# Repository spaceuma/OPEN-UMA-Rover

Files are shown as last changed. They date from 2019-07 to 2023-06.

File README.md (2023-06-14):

# UMA Open Source Rover ROS2
Open hardware and software rover developed by Malaga University

*Authors:* C.J. Pérez del Pulgar, Ricardo Sánchez Ibáñez, Patricio López Lupiañez, Francisco de Asís Delgado Rivero, Laura Marta Mantoani and Danil Rivero Pavlenko

*Contact info:* carlosperez@uma.es

*Affiliation:* University of Malaga, [Space Robotics Lab](https://www.uma.es/robotics-and-mechatronics/info/107542/robotica-espacial/)

## Overview
The OpenUmaRov is an open source mobile robotic platform that allows anyone to build it with a maximum cost of 700€, taking into account that the Reach M+ GPS can be replaced with whatever GPS that works with NMEA sentences: just connecting it to the Raspberry Pi through USB port, thanks to the ROS node the GPS can publish NMEA sentences in different topics. This means that, replacing the Reach M+ with a cheaper one, the rover can be built with a maximum cost of 500 €. 

The platform is based on commercial components that can be acquired by Internet. This project involves students and researchers to improve the development of the platform. Moreover, it can be used for teaching and research activities that involves mechanical, engineering, software, electronics and robotics.

## ROS2 

An adaptation of the original code to ROS2 Humble has been developed. This enables the use of the Rover with the Middleware ROS2. 

rover_ros2

### Guide

First you need to setup your package and your workspace. Use the package in this repository inside the workspace.

Then make sure to source the package and build the workspace.
```
 source install/setup.bash
 colcon build
```

### Troubleshooting

Issues might appear while setting up your workspace.

- setuptools 58.2 for colcon build sterr output error due to deprecated version.

https://answers.ros.org/question/396439/setuptoolsdeprecationwarning-setuppy-install-is-deprecated-use-build-and-pip-and-other-standards-based-tools/

```
pip install setuptools==58.2.0
```

Install serial
Guide: https://create.arduino.cc/projecthub/ansh2919/serial-communication-between-python-and-arduino-e7cce0

```
pip install pyserial
```

Info. about the Twist format for the msg variable which holds the data received from the topic.

http://docs.ros.org/en/noetic/api/geometry_msgs/html/msg/Twist.html

### Running the node

To run the node once sourced and built.

```
ros2 run rov_node_pkg ROS2UMARov
```

## Rover URDF

In order to test the Rover in a simulated environment, a URDF file of the OpenUMARov has been developed.

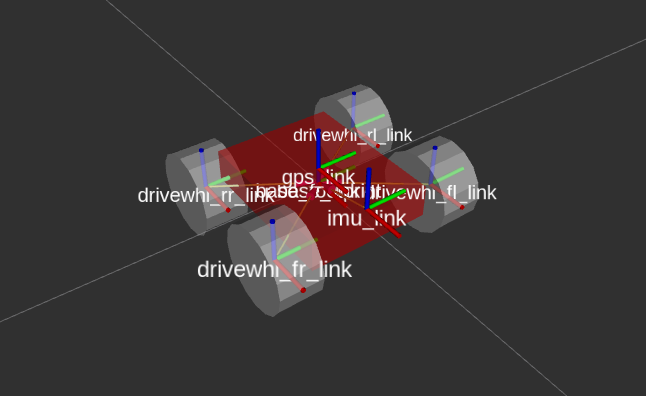
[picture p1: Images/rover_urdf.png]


## Rover SDF

To implement Rover simulations on Gazebo, it is necessary to develop the SDF Model of it. 

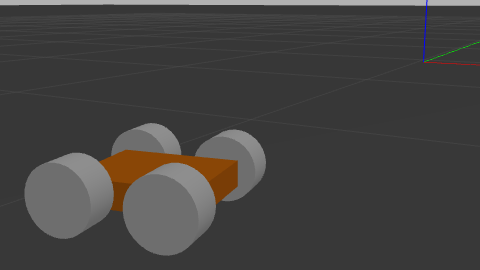
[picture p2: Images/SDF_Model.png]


This model uses the following plugins.

- GPS Plugin to simulate such in the simulation environment.
- IMU to simulate the orientation of the Rover.
- Differential drive Model to implement the movement of the Rover 
- Joint State Publisher to know wheels state.

An alternative for NAV2 has been implemented as en extended model.

## Joystick Control

A good way to easily control the Rover is by using the Teleoperation Joystick Control.

By default, it uses the ```ps3_config.yaml``` file.

To test this package a F-710 Game Pad with a USB with Bluetooth connection was used, even though the ```.config``` file is for the PS3 Joystick. If you wish to use a Bluetooh joystick control, you have to edit the directory of the connection to rather the Bluetooth direction, using a USB connection is recommended nonetheless.

To use it with the PC the following changes should be done:

- Add permissions to read/write Serial: 

```
sudo adduser $USER $(stat --format="%G" /dev/ttyACM0)
```

- Build the package with the following command:

```
colcon build --allow-overriding teleop_twist_joy
```

PS3 is default, to run for another config (e.g. xbox) use this:

```
ros2 launch teleop_twist_joy teleop-launch.py
```

Note: this launch file also launches the joy node so do not run it separately.

Only if required:

- Uninstall the default joystick teleop. from ROS2 Lib. Head to opt/ros/lib and remove the file teleop_twist_joy. 
- The last step is due to ROS2 using the config. of the default driver and its parameters instead of your package.
- Launch the driver as normally.

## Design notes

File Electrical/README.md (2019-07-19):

# OPEN-UMA-Rover/Electrical
In this folder there are the files for the PCB board in Eagle, version 7.6.0.

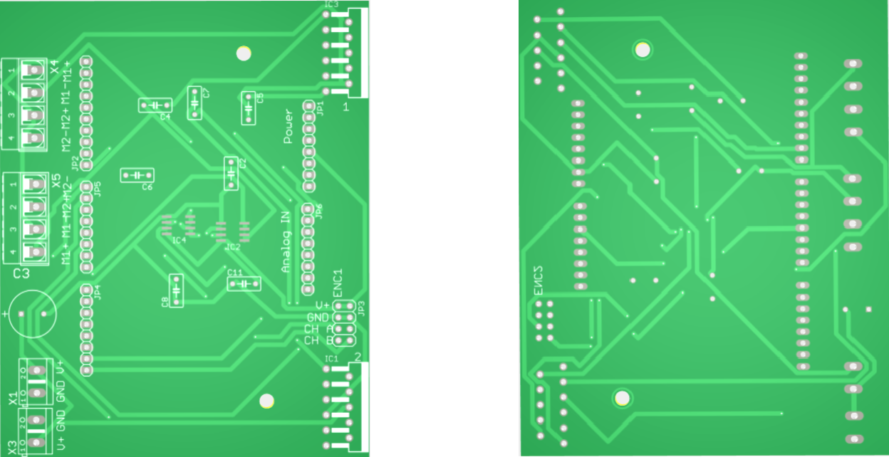
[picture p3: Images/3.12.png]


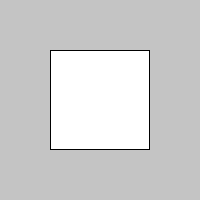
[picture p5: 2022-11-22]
Software/SDF_URDF/OpenUMA_NAV2/maps/empty_room.png

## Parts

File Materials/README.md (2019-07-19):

# OPEN-UMA-Rover
In this folder there is an Excel file which includes all the componentes needed to build the platform. Also, it is included the price, the link to buy each component and the Farnell code in case it exists.

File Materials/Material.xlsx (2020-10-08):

Component | Quantity | Farnell | Link to buy | PRICE (€)
Chasis + 4 wheels + 4 engines | 1 |  |  | 247.64
Encoder Lynxmotion | 2 |  | https://www.robotshop.com/es/es/codificador-motor-cuadratura-v2-lynxmotion-con-cable.html | 69.44
Arduino Mega 2560 | 1 |  |  | 16.95
Fuse holder | 1 |  |  | 0.5
Fuse 4A | 1 |  |  | 0.1
Connector 2.5mm | 1 |  |  | 1.06
Rechargeable battery NiMH 12 Vdc 2800 mAh | 1 |  |  | 48.99
Capacitor 1uF | 1 | 2112910 |  | 0.28
Capacitor 220uF | 1 | 1219481 |  | 0.75
Capacitor 10nF | 4 | 1141772 |  | 0.76
Capacitor 1nF | 2 | 1902259 |  | 0.78
LM18200T | 2 | 1468979 |  | 31.16
ACS712-LC | 2 | 1329623 |  | 8.18
Pin header 2X04 | 1 | 1593441 |  | 0.04
Connector AK500/2 | 2 | 2493622 |  | 0.6
Connector AK500/4-H | 2 | 2490940 |  | 3.8
Pin header 1X08 | 4 | 1593416 |  | 1.32
Pin header 1X10 | 1 | 1593417 |  | 0.4
GPS Reach M+ | 1 |  | https://emlid.com/reach/ | 227.78
Raspberry PI 3 B+ | 1 | 2842228 | https://es.farnell.com/raspberry-pi/rpi3-modbp/ordenador-monoplaca-raspberry/dp/2842228 | 32.46
Regulador Step-Down 5V/3.2A (D36V28F5) | 1 |  | https://tienda.bricogeek.com/convertidores-de-voltaje/1335-regulador-step-down-5v32a-d36v28f5.html | 10.95
 |  |  | TOTAL | 703.94
 |  |  |  |  | TOTAL

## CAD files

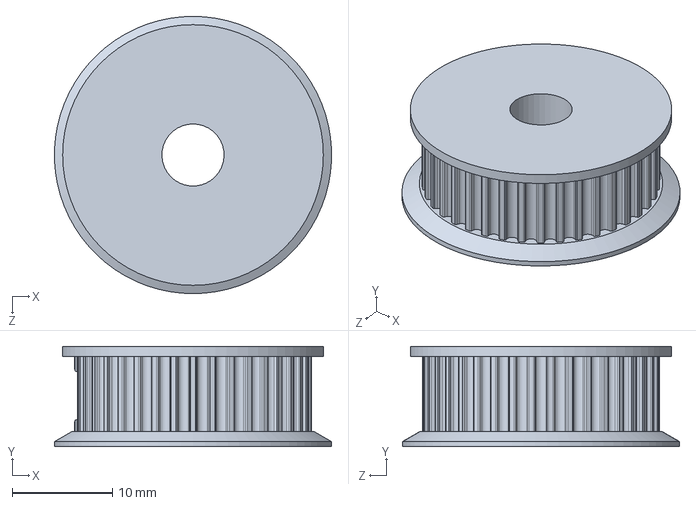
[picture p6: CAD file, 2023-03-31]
Materials/Impresiones/Engranajes Correa/Engranaje.SLDPRT
27.6 x 10.0 x 27.7 mm

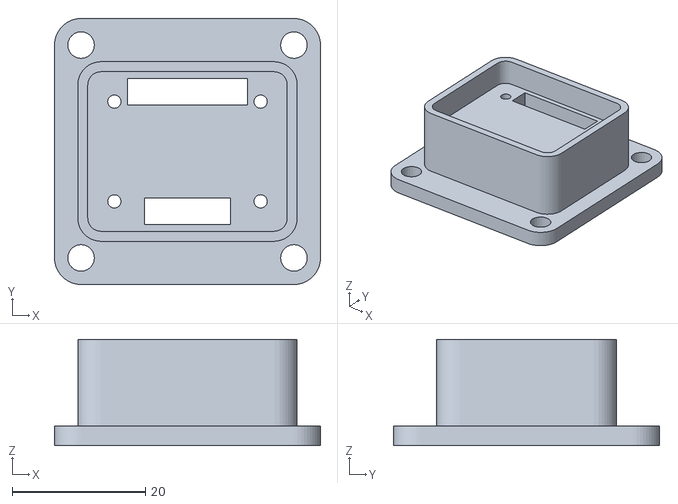
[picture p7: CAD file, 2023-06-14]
Materials/Impresiones/imu_holder.stl
40.0 x 40.0 x 16.0

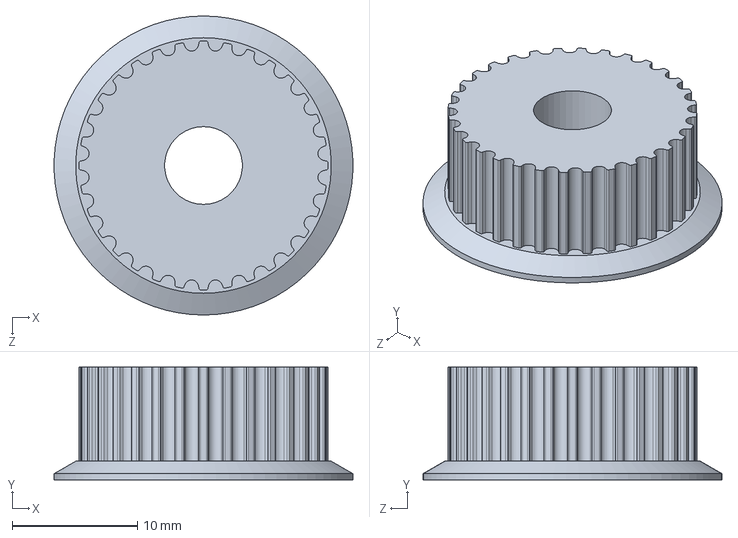
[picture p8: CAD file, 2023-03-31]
Materials/Impresiones/Engranajes Correa/gt2-parametric-pulley.SLDPRT
23.8 x 9.00 x 23.8 mm

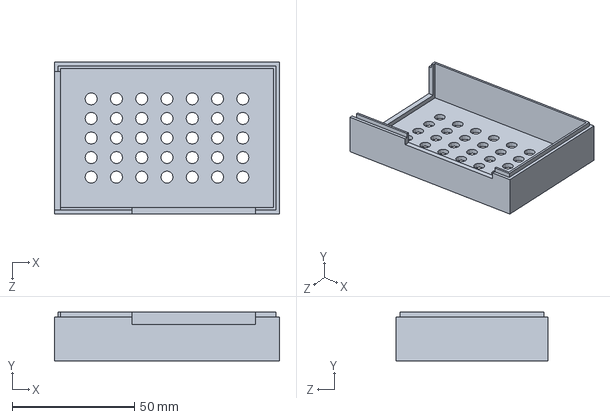
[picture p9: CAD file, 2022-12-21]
Materials/Impresiones/SoporteRasp3.SLDPRT
92.0 x 20.0 x 62.0 mm

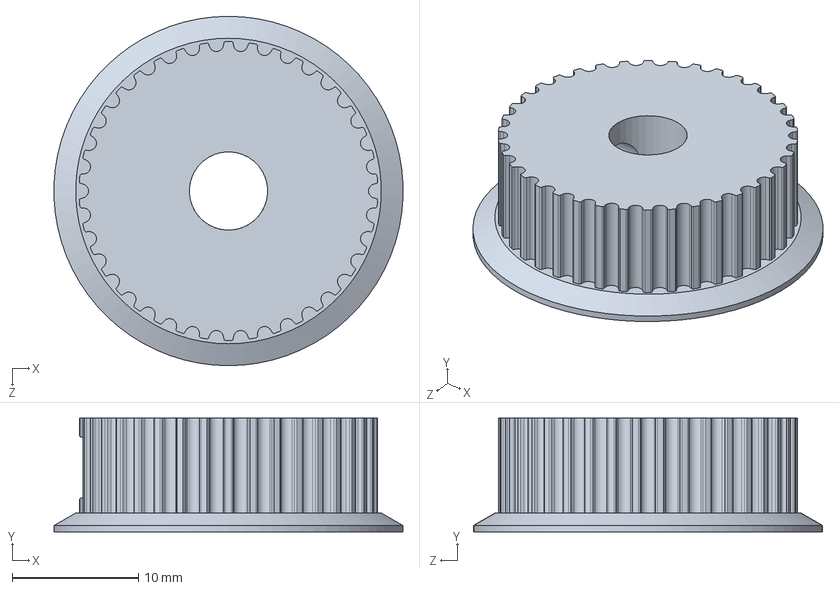
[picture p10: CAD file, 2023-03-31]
Materials/Impresiones/Engranajes Correa/Engranaje_Sin_Borde.SLDPRT
27.6 x 9.00 x 27.7 mm

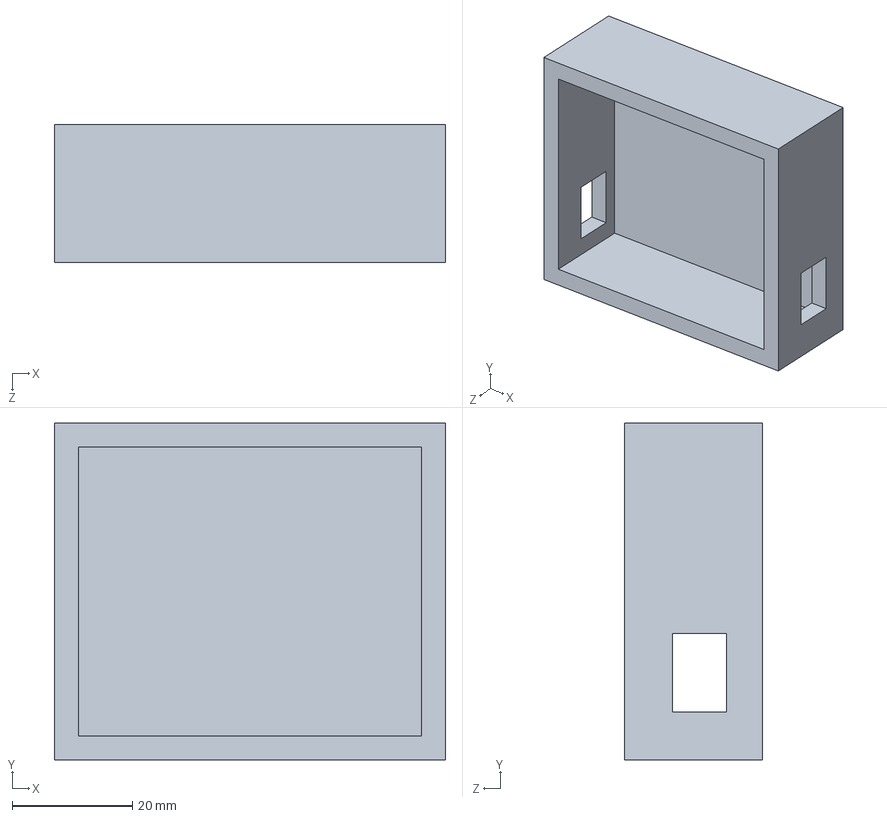
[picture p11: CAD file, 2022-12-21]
Materials/Impresiones/gps_corregido.SLDPRT
65.0 x 56.0 x 23.0 mm

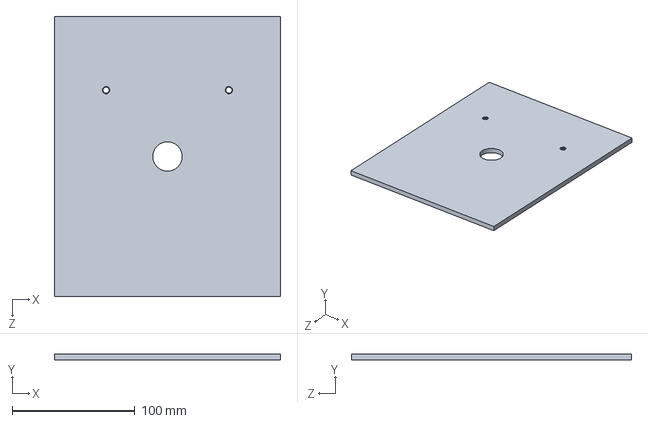
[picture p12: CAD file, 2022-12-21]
Materials/Impresiones/tapa_principal.SLDPRT
184.0 x 5.00 x 228.0 mm

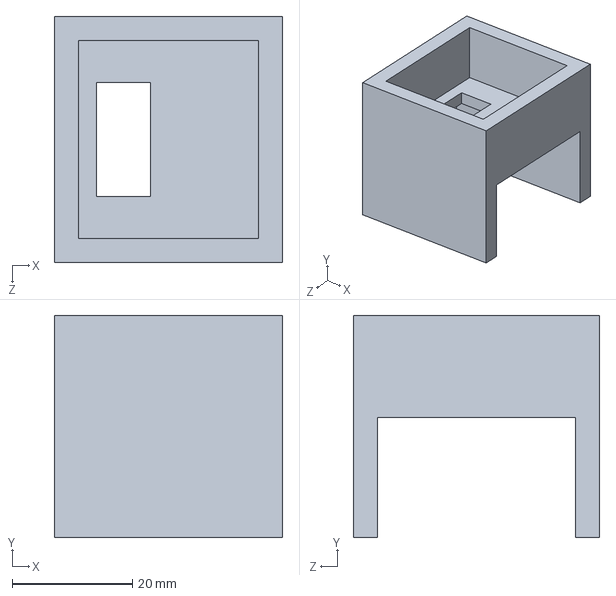
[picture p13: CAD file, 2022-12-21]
Materials/Impresiones/imu_corregido.SLDPRT
38.0 x 37.0 x 41.0 mm

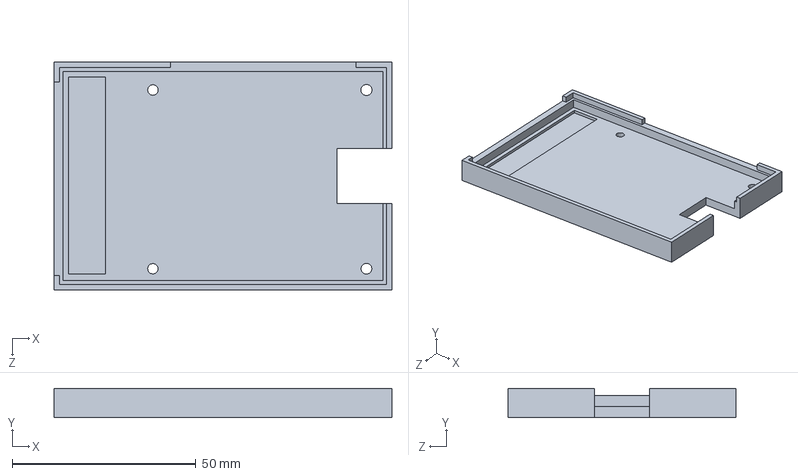
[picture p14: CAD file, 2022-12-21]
Materials/Impresiones/SoporteRasp3.1.SLDPRT
92.0 x 8.00 x 62.0 mm

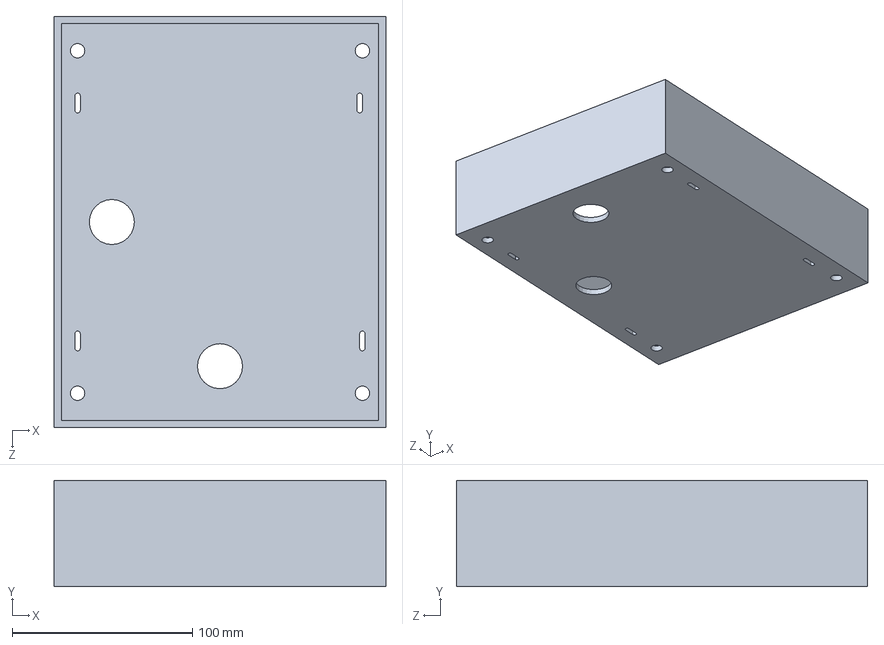
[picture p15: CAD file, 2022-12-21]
Materials/Impresiones/caja_principal.SLDPRT
184.0 x 59.0 x 228.0 mm

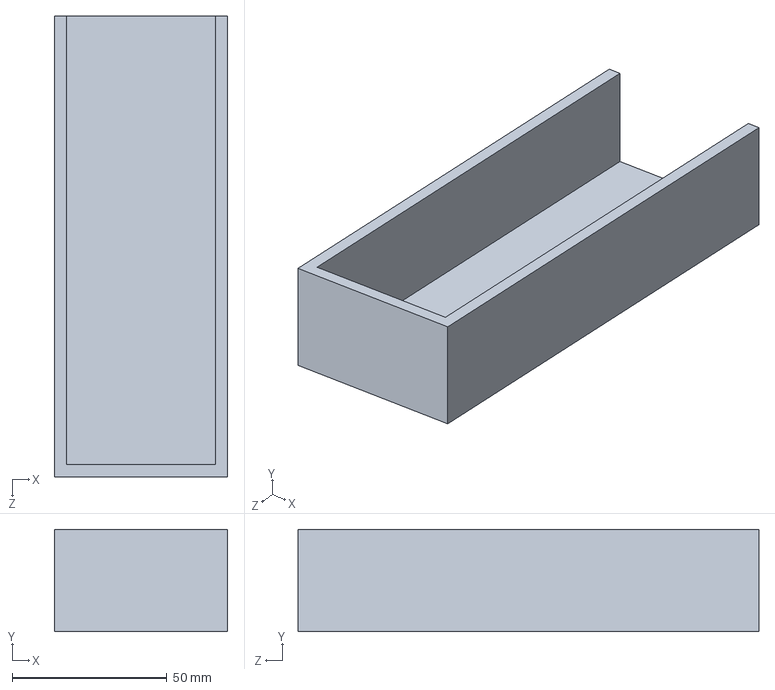
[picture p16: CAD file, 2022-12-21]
Materials/Impresiones/bateria.SLDPRT
56.0 x 33.0 x 149.0 mm

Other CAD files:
Materials/Impresiones/SoporteRasp3.1.STL
Materials/Impresiones/SoporteRasp3.STL

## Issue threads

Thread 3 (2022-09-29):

Implementar en ROS2 el control del vehículo

carlibiri, 2022-09-29:
Adaptar el código Python del nodo ROS para que se pueda conectar con Nav2.
Lo que no se pueda conectar con Nav2 se deja en un topic por si nos sirviera más adelante.

carlibiri, 2022-10-06:
Pendiente probarlo con el vehículo real.

Danilrivero, 2022-10-10:
Se ha probado el funcionamiento del nodo cargando a su vez el archivo .ino en la Mega 2560 **y funciona**.

Debido a los continuos cambios de HW que ha sufrido el Rover por los proyectos que ha tenido, indicar que el cambio más importante es que el orden de los encoders conectados a la Arduino es inverso, donde la posición del encoder 1 va la del 2 y viceversa.

carlibiri, 2022-10-13:
Las ruedas se mueven.

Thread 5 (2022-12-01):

Diseñar y fabricar caja que contenga los sensores

carlibiri, 2022-12-01:
Diseñar y fabricar caja que contenga los sensores fuera del chasis del rover.

Danilrivero, 2022-12-07:
Para realizar la caja se ha decidido dieñar de forma modular para que la impresión de todas las piezas sea más cómoda. Luego colocaré todo en su posición concreta y lo pondré a prueba.

Se tienen las siguientes piezas:

- [x] Caja de Raspberry Pi 4
- [x] Caja de batería
- [x] Caja y soporte de IMU
- [ ] Caja de GPS
- [ ] Caja principal
- [ ] Tapa de Caja

La idea es tener compartimentos modulares para cada cosa. Se tendría una caja que taparía el compartimento inferior de Arduino y PCB. Habrían unos orificios por donde entrarían 4 cables:

1. Cable de Arduino
2. Alimentación USB-C
3. Alimentación principal
4. Alimentación del HUB

Esta caja debe de ser robusta y encima habría una tapa con los soportes de GPS e IMU para que a través de un orificio se comuniquen con la RP también. Actualmente ya hay piezas hechas y estoy en proceso de realizar el resto.

Danilrivero, 2022-12-15:
Todas las piezas están hechas e impresas salvo la caja principal que es la siguiente:

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

Tarda un total de 34h en imprimirse y la impresora sigue dando problemas. Voy a desmontar el calentador del extrusor aunque no se si es la solución intentar montarlo de nuevo todo. Voy a hablar con la gente en la nave para ver si puedo poner la pieza ahí a imprimir.

Danilrivero, 2022-12-21:
Todas las piezas diseñadas e impresas.

Danilrivero, 2022-12-21:
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

Closed 2023-01-26.

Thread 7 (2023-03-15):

Gomas de agarre para OPENUMA

Danilrivero, 2023-03-15:

Danilrivero, 2023-03-15:
Estabamos analizando como hacer que las ruedas se conecten para que tengan tracción. Entre los ejes de las ruedas apenas hay sitio y no es viable añadir nada. Hemos pensado en las siguiente gomas que irían entre las ruedas a forma de oruga de tanque:

https://www.amazon.es/Elasticas-Resistencia-Ejercicios-entrenamiento-fisioterapia/dp/B016A9IUWY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

La circunferencia en el OPENUMA es de 69 cm entre las ruedas (distancia entre centro de circunferencias * 2 + 2*pi*R) y estas gomas son de 60 cm, así que vienen genial para que queden estiradas y agarradas, y tienen relieve suficiente además del que nosotros le añadamos para poder generar una buena tracción.

He analizado opciones de orugas de tanque directamente pero son o caras o no existe alguna sin sujeciones internas pensadas para tanques unicamente. Creo que ese tipo de gomas son la opción más factible, luego sobre ella podemos añadir algún tipo de relieve.

SSUrdiales, 2023-03-16:
He estado mirando diferentes alternativas para la cadena. Creo que hay que buscar que tenga rugosidad para que agarre bien al terreno:

https://www.amazon.es/Harilla-Montaje-Pl%C3%A1stico-Extra%C3%ADble-Bricolaje/dp/B07QQNC9WW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

https://www.amazon.es/PRDECE-neum%C3%A1tico-Accesorios-neum%C3%A1ticos-veh%C3%ADculos/dp/B0BCDZ3F9T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

https://www.amazon.es/DNKKQ-Accesorios-Calidad-Cadena-orugas/dp/B09J2HLFFX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

carlibiri, 2023-03-16:
Intentamos ver si podemos encajar algo entre los ejes.

Danilrivero, 2023-03-21:
Considerando la distancia entre ejes, se tiene una distancia de 162 mm, por tanto la goma debe tener las siguientes características:

- 324 mm de longitud

- 6-8 mm de ancho

He intentado plantear la posibilidad de desarrollarlo usando la goma de la impresora que es resistente y puedo crear la dentadura a forma de engranaje en los dos ejes para una mayor sujeción.

Voy a buscar en Internet modelos de gomas con esas características.

Danilrivero, 2023-03-22:
Por un lado se ha probado a pegar la goma y estamos a la espera de que seque para echarlo a rodar.

Por otro he analizado las correas cerradas:

1. El tamaño de la correa debe ser de como mínimo 324 mm, por lo tanto el siguiente valor **estándar** de correas es el de 400 mm.

2. La longitud entre ejes es de 162 mm, por lo tanto la distancia total es de 324 mm. los otros 76 mm se tratan de los dos medio arcos de los engranajes, por lo que la mitad del perimetro de cada engranaje debe ser de 38 mm.

3. 76 mm = 2*pi*r -> r = 12.09 mm, por tanto el diametro del engranaje debe ser de 24 mm. Lo cual es un tamaño muy factible y que voy a rediseñar.

He encontrado varias opciones en Amazon que llegan rápido:

- La más barata y con mas unidades de correas de 400 mm:

https://www.amazon.es/distribuci%C3%B3n-accesorios-impresora-GT2-6-400MM-transmisi%C3%B3n/dp/B085QH1C4Y

- El resto de opciones son más caras:

https://www.amazon.es/correa-dentada-cerrada-sincronizada-longitud/dp/B07RWM2SPN?th=1

- En otras páginas Web se pueden comprar por unidad más baratas:

https://createc3d.com/es/correas-y-poleas/649-correa-cerrada-gt2-200-dientes-400-mm-longitud.html

En AliExpress las que más pronto llegan son en Abril-Mayo y valen casi que lo mismo.

carlibiri, 2023-03-22:
Acabo de pedir el primero de amazon, llegarán el lunes...

El mié, 22 mar 2023 a las 11:22, Danil Pavlenko ***@***.***>)
escribió:

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

--
____________________________________________________________________________

Carlos J. Pérez del Pulgar Mancebo
Space Robotics Lab
Department of Systems Engineering and Automation
UNIVERSIDAD DE MALAGA
www.isa.uma.es/cperez
____________________________________________________________________________

Danilrivero, 2023-03-22:
Los engranajes a utilizar que he descrito son los siguientes:

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

Se trata de un GT2 de 42 dientes, que es lo ideal para la correa de 400 mm.

Los tornillos prisioneros son los siguientes que debo buscar alguna opción más barata:

- Una caja con todo tipo de 20 piezas incluyendo el nuestro:

https://www.amazon.es/Bigxin-Tornillos-Prisioneros-Hexagonal-Prisionero/dp/B092ZG9QZR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

- 10 piezas de las que necesitamos pero caro:

https://www.amazon.es/sourcing-map-Tornillos-prisioneros-hexagonales/dp/B07GZD36YP

Voy a buscar opciones más baratas para mañana en Farnell o Mouser

carlibiri, 2023-03-22:
Pedida la caja....

El mié, 22 mar 2023 a las 14:54, Danil Pavlenko ***@***.***>)
escribió:

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

--
____________________________________________________________________________

Carlos J. Pérez del Pulgar Mancebo
Space Robotics Lab
Department of Systems Engineering and Automation
UNIVERSIDAD DE MALAGA
www.isa.uma.es/cperez
____________________________________________________________________________

Danilrivero, 2023-03-23:
He conseguido una correa de las que se han pedido para probarla y en efecto he verificado que los engranajes usados son correctos, he corregido los tamaños y los dientes para que ahora si funcione.

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

La correa queda bastante tensa y el eje de la rueda entra bien, así que solo queda esperar a que lleguen más correas y verificar su montaje completo para salir.

carlibiri, 2023-03-30:
@Danilrivero sube el diseño de la pieza al repositorio de openUMA.

Closed 2023-04-11.

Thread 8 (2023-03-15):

IMU BNO055 para OPENUMAROV

Danilrivero, 2023-03-15:

Danilrivero, 2023-03-15:
Tal y como hemos comentado con Laura, hace falta una nueva IMU con la idea de que tenga Driver de ROS2 ya hecho para su uso directo y más cómodo. La chica del TFG propusó la BNO055 que en efecto tiene Driver de ROS2.

https://tienda.bricogeek.com/medicion-inercial-imu/802-sensor-inercial-absoluto-9-dof-bno055.html

He probado el paquete y parece que está todo en orden y funcionaría con adaptador UART to USB:

https://github.com/flynneva/bno055

Siendo el adaptador el siguiente:

https://www.amazon.es/TECNOIOT-CP2104-Connector-Module-Converter/dp/B07N978W56

Con el siguiente conexionado con el adaptador:

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

En caso de que necesite Drivers para detectar el USB son los siguientes:

https://www.silabs.com/developers/usb-to-uart-bridge-vcp-drivers

Laura ha comunicado ya todo esto para su compra pero lo dejo aquí para que se quede guardado.

Danilrivero, 2023-03-15:
Sería conveniente desarrollar un modelo 3D a imprimir a forma de Wrapper para dejar la IMU fijada en una posición dentro del tanque o el OPENUMA, siendo el CAD de la IMU para tener un modelo en el que basarse el siguiente:

https://grabcad.com/library/adafruit-bno055-1

carlibiri, 2023-03-30:
Llega el Viernes...

carlibiri, 2023-04-20:
Pendiente probarla para comprar otra...

Danilrivero, 2023-04-21:
He verificado que la IMU funciona correctamente mediante un pequeño código de prueba en Arduino:

[imu_bno.zip](https://github.com/spaceuma/OPEN-UMA-Rover/files/11294345/imu_bno.zip)

Echando a correr el driver a una velocidad de 9600 baudios me surge el siguiente problema.

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

He dado todos los permisos debidamente para que el adaptador no tenga problemas para conectarse, aunque sigue ocurriendo. He escrito un issue en el repositorio oficial para recibir alguna ayuda ya que parece que la comunicación no sucede de forma bidireccional.

Danilrivero, 2023-04-24:
He conseguido solucionar el problema.

El problema siguiendo mi issue en https://github.com/flynneva/bno055 es que parece que en la comunicación UART la recepción de datos no era del tamaño de bytes que debía ser. He corregido dicho error y crearé un repositorio con esta información para que quede almacenado.

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

A la espera de verificar todo aunque este issue quedaría resuelto.

Danilrivero, 2023-04-25:
He creado un repositorio para toda la información, cambios y drivers aunque no creo que fueran los drivers el problema sino la recepción de bytes.

Danilrivero, 2023-04-27:
Resultado final:

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

Soporte con tornillos para fijar la IMU.

Closed 2023-04-27.

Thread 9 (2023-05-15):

Mejoras generales para ultimar OPENUMA Rover

Danilrivero, 2023-05-15:

Danilrivero, 2023-05-15:
[Teleoperation_Platform_ROS2.txt](https://github.com/spaceuma/OPEN-UMA-Rover/files/11477049/Teleoperation_Platform_ROS2.txt)

Danilrivero, 2023-05-19:
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

Mejoras finales del OPENUMA hechas

Closed 2023-05-25.

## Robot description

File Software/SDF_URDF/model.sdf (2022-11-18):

<?xml version="1.0" ?>
<sdf version="1.5">
  <model name="basic_mobile_bot">  
  <static>false</static>

  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
  <pose>0.0 0.0 0.0 0.0 0.0 0.0</pose>
  <link name="base_footprint"/>

  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
  <link name="base_link">
    
    <inertial>
      <mass>2</mass>
      <inertia>
        <ixx>0.00545</ixx>
        <ixy>0</ixy>
        <ixz>0</ixz>
        <iyy>0.00841</iyy>
        <iyz>0</iyz>
        <izz>0.0131</izz>
      </inertia>
    </inertial>

    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
  </link>

  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
  <link name="imu_link">
    <gravity>true</gravity>
    <sensor name="bmb_imu" type="imu">
      <always_on>true</always_on>
      <update_rate>100</update_rate>
      <visualize>true</visualize>
      <imu>
        <orientation>
          <x>
            <noise type="gaussian">
              <mean>0.0</mean>
              <stddev>2e-3</stddev>
            </noise>
          </x>
          <y>
            <noise type="gaussian">
              <mean>0.0</mean>
              <stddev>2e-3</stddev>
            </noise>
          </y>
          <z>
            <noise type="gaussian">
              <mean>0.0</mean>
              <stddev>2e-3</stddev>
            </noise>
          </z>
        </orientation>
        <angular_velocity>
          <x>
            <noise type="gaussian">
              <mean>0.0</mean>
              <stddev>2e-4</stddev>
            </noise>
          </x>
          <y>
            <noise type="gaussian">
              <mean>0.0</mean>
              <stddev>2e-4</stddev>
            </noise>
          </y>
          <z>
            <noise type="gaussian">
              <mean>0.0</mean>
              <stddev>2e-4</stddev>
            </noise>
          </z>
        </angular_velocity>
        <linear_acceleration>
          <x>
            <noise type="gaussian">
              <mean>0.0</mean>
              <stddev>1.7e-2</stddev>
            </noise>
          </x>
          <y>
            <noise type="gaussian">
              <mean>0.0</mean>
              <stddev>1.7e-2</stddev>
            </noise>
          </y>
          <z>
            <noise type="gaussian">
              <mean>0.0</mean>
              <stddev>1.7e-2</stddev>
            </noise>
          </z>
        </linear_acceleration>
      </imu>
      <plugin name="basic_mobile_bot_imu" filename="libgazebo_ros_imu_sensor.so">
        <initial_orientation_as_reference>false</initial_orientation_as_reference>
        <frame_name>imu_link</frame_name>
        <ros>
          <namespace>/imu</namespace>
          <remapping>~/out:=data</remapping>
        </ros>
      </plugin>
    </sensor>
  </link>

  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
  <link name="gps_link">
    <sensor name="bmb_gps" type="gps">
      <always_on>true</always_on>
      <update_rate>10.0</update_rate>
      <gps>
        <position_sensing>
          <horizontal>
            <noise type="gaussian">
              <mean>0.0</mean>
              <stddev>1e-2</stddev>
            </noise>
          </horizontal>
          <vertical>
            <noise type="gaussian">
              <mean>0.0</mean>
              <stddev>1</stddev>
            </noise>
          </vertical>
        </position_sensing>
      </gps>
      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
      <plugin name="basic_mobile_bot_gps" filename="libgazebo_ros_gps_sensor.so">
        <ros>
          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
          <remapping>~/out:=gps/fix</remapping>
        </ros>
      </plugin>
    </sensor>
  </link>

  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
  <link name="drivewhl_rl_link">

    <inertial>
      <mass>0.3</mass>
      <inertia>
        <ixx>0.000354</ixx>
        <ixy>0</ixy>
        <ixz>0</ixz>
        <iyy>0.000354</iyy>
        <iyz>0</iyz>
        <izz>0.00054</izz>
      </inertia>
    </inertial>

    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
    <pose>-0.084 0.1175 0.058 0 1.570796 1.570796</pose>
    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
  </link>

  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
  <link name="drivewhl_rr_link">

    <inertial>
      <mass>0.3</mass>
      <inertia>
        <ixx>0.000354</ixx>
        <ixy>0</ixy>
        <ixz>0</ixz>
        <iyy>0.000354</iyy>
        <iyz>0</iyz>
        <izz>0.00054</izz>
      </inertia>
    </inertial>

    <pose>-0.084 -0.1175 0.058 0 1.570796 1.570796</pose>
    
    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
  </link>

   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
  <link name="drivewhl_fl_link">

    <inertial>
      <mass>0.3</mass>
      <inertia>
        <ixx>0.000354</ixx>
        <ixy>0</ixy>
        <ixz>0</ixz>
        <iyy>0.000354</iyy>
        <iyz>0</iyz>
        <izz>0.00054</izz>
      </inertia>
    </inertial>

    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
    <pose>0.084 0.1175 0.058 0 1.570796 1.570796</pose>
    
    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
  </link>

  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
  <link name="drivewhl_fr_link">

    <inertial>
      <mass>0.3</mass>
      <inertia>
        <ixx>0.000354</ixx>
        <ixy>0</ixy>
        <ixz>0</ixz>
        <iyy>0.000354</iyy>
        <iyz>0</iyz>
        <izz>0.00054</izz>
      </inertia>
    </inertial>

    <pose>0.084 -0.1175 0.058 0 1.570796 1.570796</pose>
    
    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
  </link>

  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
  
  <joint name="base_joint" type="fixed">
    <parent>base_footprint</parent>
    <child>base_link</child>
    <pose>0 0 0 0 0 0</pose>
  </joint>

  <joint name="drivewhl_rl_joint" type="revolute">
    <parent>base_link</parent>
    <child>drivewhl_rl_link</child>
    <pose>0 0 0 0 0 0</pose>
    <axis>
      <xyz>0 0 1</xyz>
    </axis>
  </joint>

  <joint name="drivewhl_rr_joint" type="revolute">
    <parent>base_link</parent>
    <child>drivewhl_rr_link</child>
    <pose>0 0 0 0 0 0</pose>
    <axis>
      <xyz>0 0 1</xyz>
    </axis>
  </joint>

    <joint name="drivewhl_fl_joint" type="revolute">
    <parent>base_link</parent>
    <child>drivewhl_fl_link</child>
    <pose>0 0 0 0 0 0</pose>
    <axis>
      <xyz>0 0 1</xyz>
    </axis>
  </joint>

    <joint name="drivewhl_fr_joint" type="revolute">
    <parent>base_link</parent>
    <child>drivewhl_fr_link</child>
    <pose>0 0 0 0 0 0</pose>
    <axis>
      <xyz>0 0 1</xyz>
    </axis>
  </joint>

  <joint name="imu_joint" type="fixed">
    <parent>base_link</parent>
    <child>imu_link</child>
    <pose>0 0 0 0 0 0</pose>
  </joint>  

  <joint name="gps_joint" type="fixed">
    <parent>base_link</parent>
    <child>gps_link</child>
    <pose>0 0 0 0 0 0</pose>
  </joint>  

 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
  <plugin name='skid_steer_drive' filename='libgazebo_ros_diff_drive.so'>

    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
    <num_wheel_pairs>2</num_wheel_pairs>
    
    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
    <left_joint>drivewhl_fl_joint</left_joint>
    <right_joint>drivewhl_fr_joint</right_joint>

    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
    <left_joint>drivewhl_rl_joint</left_joint>
    <right_joint>drivewhl_rr_joint</right_joint>

    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
    <wheel_separation>0.26</wheel_separation>
    <wheel_separation>0.26</wheel_separation>

    <wheel_diameter>0.116</wheel_diameter>
    <wheel_diameter>0.116</wheel_diameter>

    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
    <command_topic>cmd_vel</command_topic>

    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
    <max_wheel_torque>20</max_wheel_torque>
    <max_wheel_acceleration>1.0</max_wheel_acceleration>

    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
    <publish_odom>true</publish_odom>
    <publish_odom_tf>true</publish_odom_tf>
    <publish_wheel_tf>true</publish_wheel_tf>

    <odometry_topic>odom</odometry_topic>
    <odometry_frame>odom</odometry_frame>
    <robot_base_frame>base_footprint</robot_base_frame>

    <ros>
      <remapping>odom:=wheel/odometry</remapping>
    </ros>

  </plugin>

 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
  
  <plugin name="basic_mobile_bot_joint_state" filename="libgazebo_ros_joint_state_publisher.so">
    <ros>
      <remapping>~/out:=joint_states</remapping>
    </ros>
    <update_rate>30</update_rate>
    <joint_name>drivewhl_rl_joint</joint_name>
    <joint_name>drivewhl_rr_joint</joint_name>
    <joint_name>drivewhl_fl_joint</joint_name>
    <joint_name>drivewhl_fr_joint</joint_name>
  </plugin>   
  
  </model>
</sdf>

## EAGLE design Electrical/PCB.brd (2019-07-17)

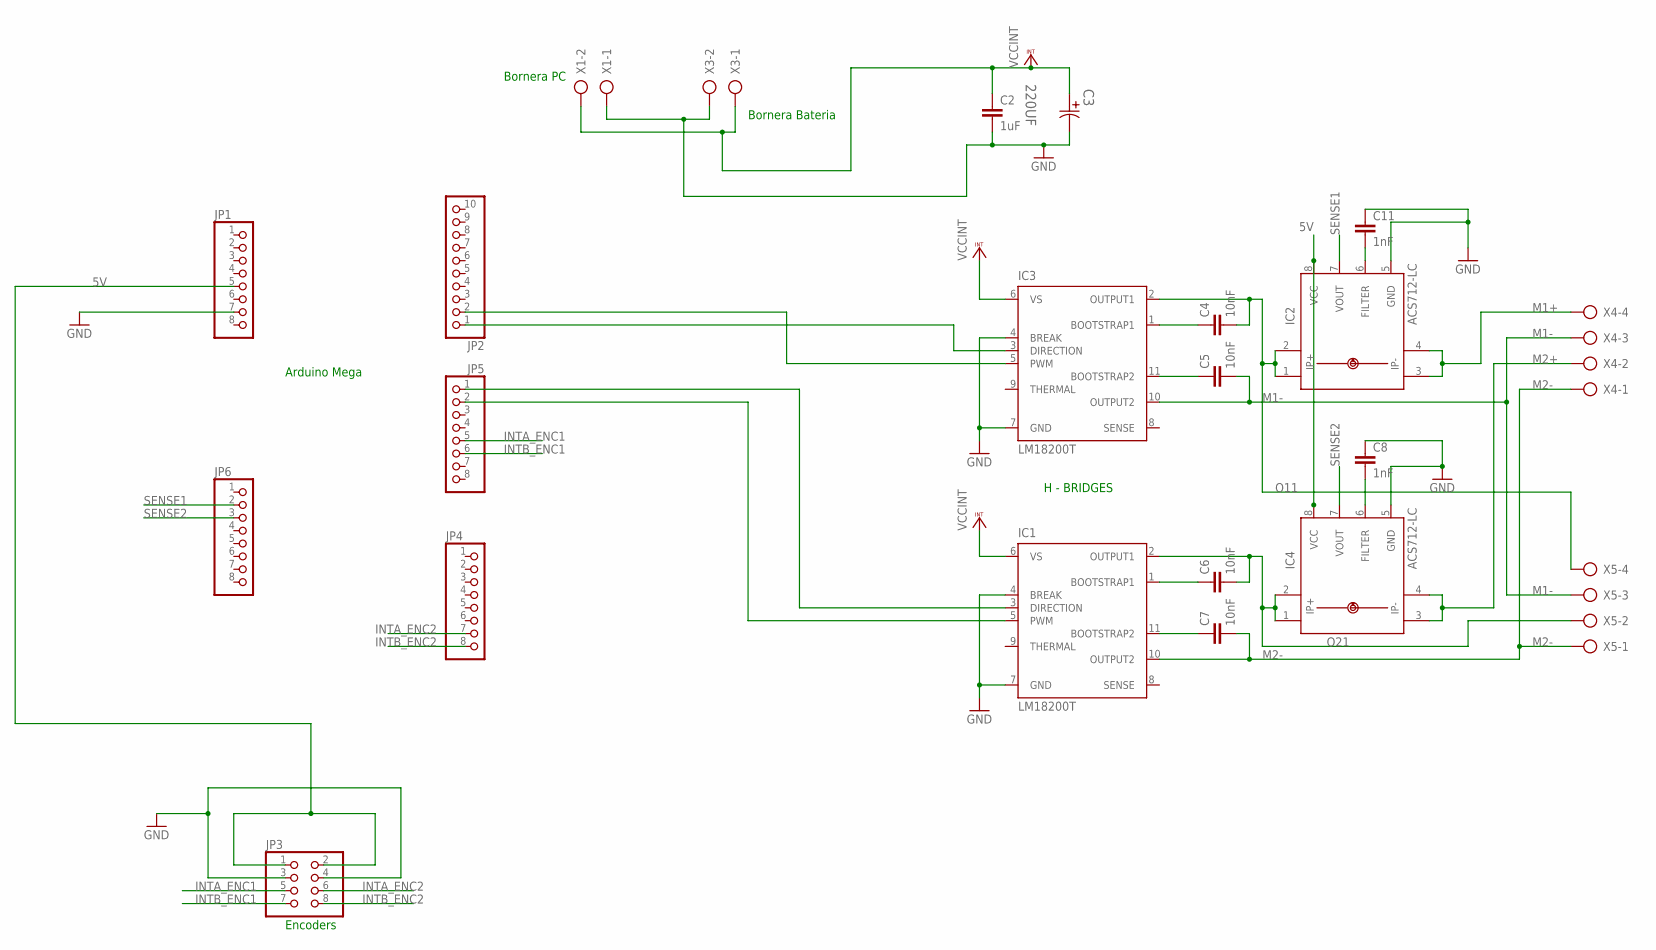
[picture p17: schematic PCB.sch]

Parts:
C2: 1uF; C050-030X075
C3: 220UF; CAPPR500-1000X3200
C4, C5, C6, C7: 10nF; C050-030X075
C8, C11: 1nF; C050-030X075
IC1, IC3: LM18200T; TO-220-11
IC2, IC4: ACS712-LC; SOIC8
JP1, JP4, JP5, JP6: PINHD-1X8; 1X08
JP2: PINHD-1X10; 1X10
JP3: PINHD-2X4; 2X04
X1, X3: AK500/2
X4, X5: AK500/4-H

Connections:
5V: IC2.8 (VCC), IC4.8 (VCC), JP1.5, JP3.1, JP3.2
GND: C2.2, C3.2, C8.1, C11.1, IC1.4 (BREAK), IC1.7 (GND), IC2.5 (GND), IC3.4 (BREAK), IC3.7 (GND), IC4.5 (GND), JP1.7, JP3.3, JP3.4, X1.1, X3.2
INTA_ENC1: JP3.5, JP5.5
INTA_ENC2: JP3.6, JP4.7
INTB_ENC1: JP3.7, JP5.6
INTB_ENC2: JP3.8, JP4.8
M1+: IC2.3 (IP-), IC2.4 (IP-1), X4.4
M1-: C5.2, IC3.10 (OUTPUT2), X4.3, X5.3
M2+: IC4.3 (IP-), IC4.4 (IP-1), X4.2
M2-: C7.2, IC1.10 (OUTPUT2), X4.1, X5.1
unnamed: IC3.3 (DIRECTION), JP2.1
unnamed: IC3.5 (PWM), JP2.2
unnamed: IC1.3 (DIRECTION), JP5.1
unnamed: C4.1, IC3.1 (BOOTSTRAP1)
unnamed: IC1.5 (PWM), JP5.2
unnamed: C8.2, IC4.6 (FILTER)
unnamed: C11.2, IC2.6 (FILTER)
unnamed: C5.1, IC3.11 (BOOTSTRAP2)
unnamed: C6.1, IC1.1 (BOOTSTRAP1)
unnamed: C7.1, IC1.11 (BOOTSTRAP2)
O11: C4.2, IC2.1 (IP+), IC2.2 (IP+1), IC3.2 (OUTPUT1), X5.4
O21: C6.2, IC1.2 (OUTPUT1), IC4.1 (IP+), IC4.2 (IP+1), X5.2
SENSE1: IC2.7 (VOUT), JP6.2
SENSE2: IC4.7 (VOUT), JP6.3
VCCINT: C2.1, C3.1, IC1.6 (VS), IC3.6 (VS), X1.2, X3.1

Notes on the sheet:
Encoders
Arduino Mega
H - BRIDGES
Bornera Bateria
Bornera PC

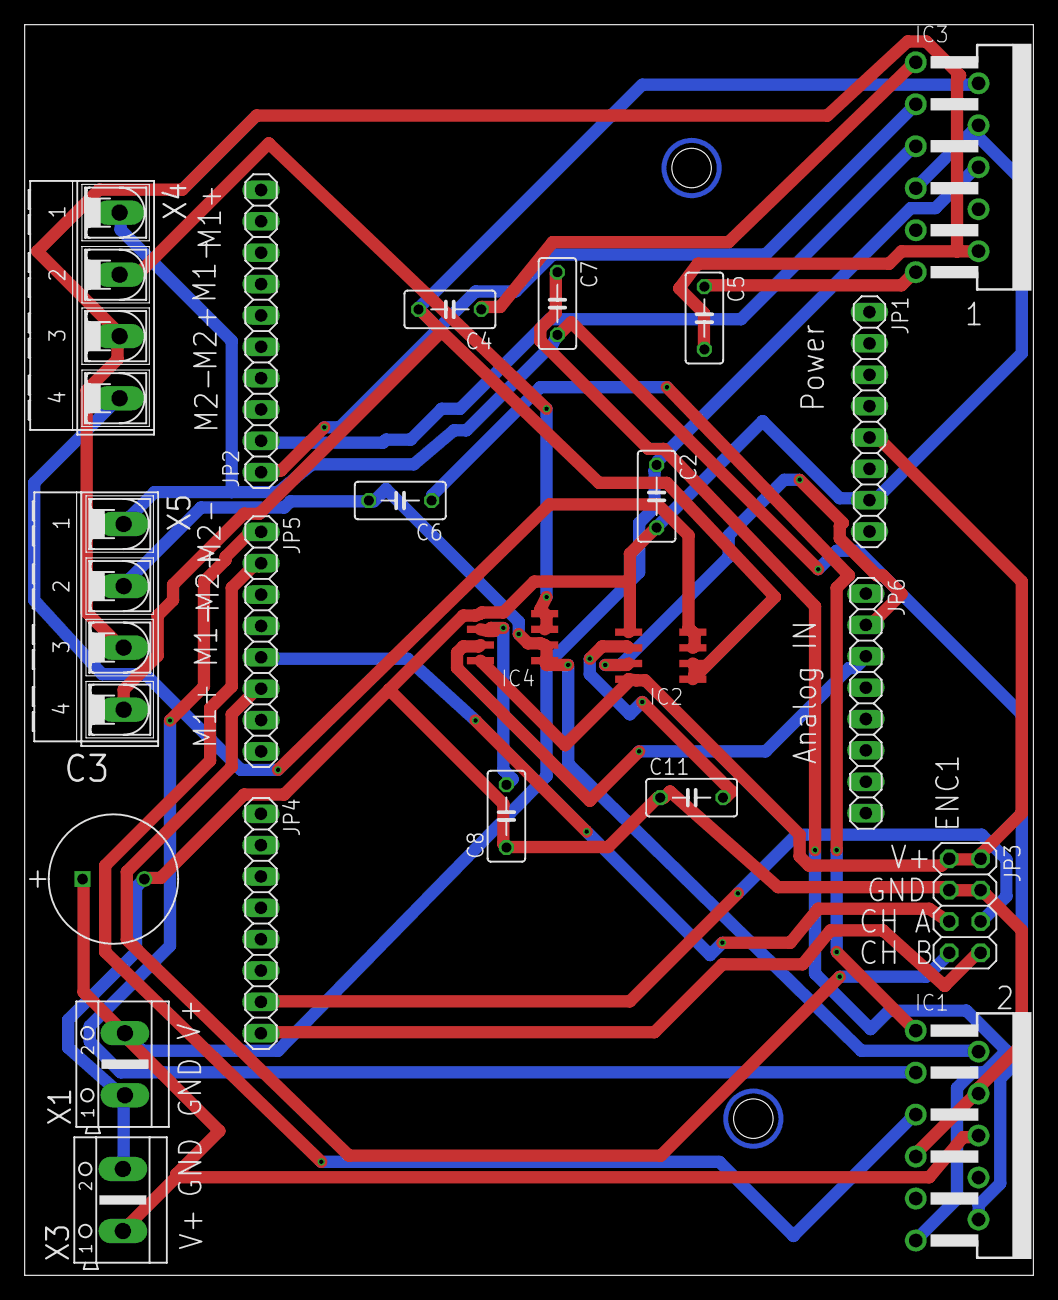
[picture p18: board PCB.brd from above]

Board: 6 copper layers, 81.7 x 101.3 mm, 22 parts (0 on the bottom side), 25 nets.

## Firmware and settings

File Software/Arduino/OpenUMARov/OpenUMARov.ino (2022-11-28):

// Código Arduino para control en posición y velocidad y lectura de corrientes de los motores de un rover.

//Librerias
#include <TimerOne.h>
#include<avr/interrupt.h>
#include<avr/io.h>
#include <SoftwareSerial.h>

//Definicion de los pines del encoder 1
#define encoder1PinA  2
#define encoder1PinB  3

//Definicion de los pines del encoder 2
#define encoder2PinA 21
#define encoder2PinB 20

//Definicion de los pines donde esta conectado la señal PWM en arduino y puentes H
#define pinPWM1 9
#define pinPWM2 6

//Definicion de los pines para la direccion de las ruedas (PWM)
#define  dirPWM1 8
#define  dirPWM2 7

//Defincion de los pines donde se encuentran los sensores de corriente.
const int sensorCurrent1 = A1;
const int sensorCurrent2 = A2;

//KP = 3, KI = 30
//Definicion de las constantes para el PID 1
#define kp1 0.5
#define ki1 20
#define kd1 0

//Definicion de las constantes para el PID 2
#define kp2 0.5
#define ki2 20
#define kd2 0

//Definicion filtro digital exponencial
#define alpha 0.6

//Corriente -- variable para lectura de corriente
float lectura_analog1;
float lectura_analog2;

//PWM -- variable para designar valor al PWM
byte valorPWM1;
byte valorPWM2;



//Variables para interrupciones
//Guarda el numero de pulsos de la rueda 1
float pulsos1;
//Guarda el numero de pulsos de la rueda 1, 10 ms antes que es el tiempo al cual esta configurada la interrupcion
float pulsos1Ant;
//Diferencia de pulsos que se han dado en los 10 ms (velpulsos=pulsos-pulsosAnt)
float velpulsos1;
//Guarda el numero de pulsos de la rueda 2
float pulsos2;
//Guarda el numero de pulsos de la rueda 2, 10 ms antes que es el tiempo al cual esta configurada la interrupcion
float pulsos2Ant;
//Diferencia de pulsos que se han dado en los 10 ms (velpulsos=pulsos-pulsosAnt)
float velpulsos2;



//Designacion del Tiempo interrupcion temporizada 10ms
unsigned long tiempoint = 10000;


//Variables globales para PID 1
int volatile sn1;
int volatile en1;
int volatile enOld1;
int volatile mn1;
int volatile mn1Old;
int volatile mn1Oldest;

//Variables globales para PID 2
int volatile sn2;
int volatile en2;
int volatile enOld2;
int volatile mn2;
int volatile mn2Old;
int volatile mn2Oldest;

//Variables para establecer limites minimo y maximo de los PID (efecto wind-up)
int volatile snmin;
int volatile snmax;

//Referencia para los PID
//Estas referencia son el numero de pulsos que se deben de dar para mantener una velocidad constante
int volatile ref1;
int volatile ref2;

//Para la recepcion de las velocidades aportadas por el nodo de ROS

//En estos dos buffers se guardan los 4 bytes que llegan por puerto serie, los 2 primeros se guardan en buffIn_1 y se corresponden 
//a la velocidad de la rueda 1, y los 2 siguientes se guardan en buffIn_2 y se corresponden a la velocidad de la rueda 2.
byte buffIn_1 [2] = {0, 0};
byte buffIn_2 [2] = {0, 0};
//Variable auxiliar para juntar los 2 bytes para obtener la referencia de velocidad de las ruedas 1 y 2 respectivamente.
byte long auxi1;
byte long auxi2;
int g;



void setup()
{

  auxi1 = 0;
  auxi2 = 0;
  ref1 = 0;
  ref2 = 0;
  
  //Inicializacion de las variables
  pulsos1 = 0;
  pulsos1Ant = 0;
  velpulsos1 = 0;
  pulsos2 = 0;
  pulsos2Ant = 0;
  velpulsos2 = 0;


  //Designacion del valor inicial del PWM (0 -- 0%, 64 -- 25%, 127 -- 50%, 191 -- 75%, 255 -- 100%)
  valorPWM1 = 0;
  valorPWM2 = 0;


  //Inicializacion de las variables de los PID
  sn1 = 0;
  en1 = 0;
  enOld1 = 0;
  mn1 = 0;
  mn1Old = 0;
  mn1Oldest = 0;
  sn2 = 0;
  en2 = 0;
  enOld2 = 0;
  mn2 = 0;
  mn2Old = 0;
  mn2Oldest = 0;
  

  //Establecimiento de unos limites ya que el motor tiene una velocidad maxima dada por sus caracteristicas.
  snmin= -600;
  snmax= 600;



  //INTERRUPCIONES EXTERNAS -- ENCODERS -- CONTADOR DE PULSOS
  //Configuracion como pines de entrada los pines donde estan los canales A y B del encoder 1.
  pinMode(encoder1PinA, INPUT);
  pinMode(encoder1PinB, INPUT);

  //Configuracion como pines de entrada los pines donde estan los canales A y B del encoder 2.
  pinMode(encoder2PinA, INPUT);
  pinMode(encoder2PinB, INPUT);


  //Configuracion de las interrupciones del encoder 1, las cuales se han configurado para que salte en disparo de subida y bajada.
  attachInterrupt(0, doEncoder1A, CHANGE);
  attachInterrupt(1, doEncoder1B, CHANGE);

  //Configuracion de las interrupciones del encoder 2, las cuales se han configurado para que salte en disparo de subida y bajada.
  attachInterrupt(2, doEncoder2A, CHANGE);
  attachInterrupt(3, doEncoder2B, CHANGE);

  //Pines de lectura de corriente como entradas.
  pinMode(sensorCurrent1, INPUT);
  pinMode(sensorCurrent2, INPUT);  

  //INTERRUPCION TIEMPO (TIMER1) -- CALCULO VELOCIDAD
  //Configuracion interrupcion temporizada para calculo de la velocidad.
  //Intervalo de tiempo de disparo en microsegundos.
  Timer1.initialize(tiempoint);

  //Attach de la interrupcion con el servicio de gestion
  Timer1.attachInterrupt(ISR_cVelocidad);


  //PWM -- TRANSMITE POTENCIA Y DIRECCION
  //Configuracion como salida los pines de direccion de las ruedas.
  pinMode(dirPWM1, OUTPUT);
  pinMode(dirPWM2, OUTPUT);
  //Configuración de velocidad inicial deseada de las ruedas en funcion del valorPWM
  analogWrite(pinPWM1, valorPWM1);
  analogWrite(pinPWM2, valorPWM2);


  //Habilitacion de interrupciones
  //Habilita todas las interrupciones a nivel de programacion del microcontrolador.
  sei();
  //Habilita todas las interrupciones a nivel de programación de arduino.
  interrupts();
  //Inicializacion y Configuracion de la velocidad del puerto serie, la cual se ha establecido a 9600 bits/s.
  Serial.begin(115200);
  // Se definen los milisegundos maximos de espera de datos desde el puerto serie.
  Serial.setTimeout(1000);
  while (!Serial) {
    ; // Espera hasta que se conecte el puerto serie.
  }

}

void loop()
{
  //Espera hasta que halla alguna informacion disponible en el puerto serie.
  if (Serial.available())
  {
    //La funcion serial.readbytes lee datos del buffer serie y los guarda en dos variables buffer que tienen una capacidad de 2 bytes cada una.      
    Serial.readBytes(buffIn_1, 2);
    Serial.readBytes(buffIn_2, 2);
    // Espera de un segundo.
    // delay(100);

    //Espera que se envien los datos correctamente
    Serial.flush();

    //En la variable auxi1 guardamos los 2 bytes ubicados en buffIn_1, los cuales al agruparlos se corresponden con los pulsos que se tienen que dar
    //para tener la referencia de la velocidad seleccionada para el motor 1.
    auxi1 = (byte)buffIn_1[1] << 8;
    auxi1 += (byte)buffIn_1[0];
    //En la variable ref guardamos la variable auxi la cual es de tipo byte y la convertimos a tipo entero de 32 bits.
    ref1 = (long int)auxi1;
    //En la variable auxi2 guardamos los 2 bytes ubicados en buffIn_2, los cuales al agruparlos se corresponden con los pulsos que se tienen que dar
    //para tener la referencia de la velocidad seleccionada para el motor 2.
    auxi2 = (byte)buffIn_2[1] << 8;
    auxi2 += (byte)buffIn_2[0];
    //En la variable ref guardamos la variable auxi la cual es de tipo byte y la convertimos a tipo entero de 32 bits.
    ref2 = (long int)auxi2;

    //Lectura de la corriente de los motores
    lectura_analog1 = analogRead(sensorCurrent1);
    lectura_analog2 = analogRead(sensorCurrent2);

    //Envio por puerto serie a ROS2
    Serial.println(pulsos1);
    Serial.println(pulsos2);
    
    Serial.println(velpulsos1);
    Serial.println(velpulsos2); 
  
    Serial.println(ref1);
    Serial.println(ref2);
    
    // Serial.flush();

    // Se limpia el buffer, abriendo y cerrando el puerto serie.
    Serial.end();
    Serial.begin(115200);
    // Espera de un segundo
    delay(50);
  } 
  // Si no hay ninguna informacion disponible para ser recibida, se limpia el buffer y se espera hasta que llegue algun dato.
  else {
    // Se limpia el buffer, abriendo y cerrando el puerto serie.
    Serial.end();
    Serial.begin(115200);
    // Espera de un segundo.
    delay(100);  
  }
}



//Interrupciones encoder 1
//Canal A
void doEncoder1A()
{
  sei();
  interrupts();
  if (bit_is_set(PINE, 4))
  {
    if (bit_is_set(PINE, 5))
    {
      pulsos1--;
    }
    else
    {
      pulsos1++;
    }
  }
  else
  {
    if (bit_is_set(PINE, 5))
    {
      pulsos1++;
    }
    else
    {
      pulsos1--;
    }
  }
}

//Canal B
void doEncoder1B()
{
  sei();
  interrupts();
  if (bit_is_set(PINE, 5))
  {
    if (bit_is_set(PINE, 4))
    {
      pulsos1++;
    }
    else
    {
      pulsos1--;
    }
  }
  else
  {
    if (bit_is_set(PINE, 4))
    {
      pulsos1--;
    }
    else
    {
      pulsos1++;
    }
  }
}

//Interrupciones encoder 2
//Canal A
void doEncoder2A()
{
  sei();
  interrupts();
  if (bit_is_set(PIND, 0))
  {
    if (bit_is_set(PIND, 1))
    {
      pulsos2++;
    }
    else
    {
      pulsos2--;
    }
  }
  else
  {
    if (bit_is_set(PIND, 1))
    {
      pulsos2--;
    }
    else
    {
      pulsos2++;
    }
  }
}

//Canal B
void doEncoder2B()
{
  sei();
  interrupts();
  if (bit_is_set(PIND, 1))
  {
    if (bit_is_set(PIND, 0))
    {
      pulsos2--;
    }
    else
    {
      pulsos2++;
    }
  }
  else
  {
    if (bit_is_set(PIND, 0))
    {
      pulsos2++;
    }
    else
    {
      pulsos2--;
    }
  }
}



//Interrupcion para obtencion de la velocidad (salta cada 10ms)
void ISR_cVelocidad()
{
  sei();
  interrupts();
  //Calculo la diferencia de pulsos que se dan en 10 ms en la rueda 1.
  velpulsos1 = pulsos1 - pulsos1Ant;
  //Se actualiza el valor de los pulsos que se llevan.
  pulsos1Ant = pulsos1;

  //Calculo la diferencia de pulsos que se dan en 10 ms en la rueda 2.
  velpulsos2 = pulsos2 - pulsos2Ant;
  //Se actualiza el valor de los pulsos que se llevan.
  pulsos2Ant = pulsos2;


  //Calculo del error.
  en1 = ref1 - (velpulsos1);
  en2 = ref2 - (velpulsos2);
  //Llamamiento a las funciones PID.
  PIDControl1();
  PIDControl2();
  //Llamamiento a las funciones que actuan sobre los motores.
  actuador1();
  actuador2();  
}


//Funcion PID 1
void PIDControl1()
{
  sei();
  interrupts();

  //Calculo del sumatorio del error.
  sn1 = sn1 + en1;

  //Condicionales por si el error sobresale de los limites de velocidad maxima del motor 1.
  if (sn1 > snmax)
  {
    sn1 = snmax;
  }
  else if (sn1 < snmin)
  {
    sn1 = snmin;
  }
  //Calculo del valor PWM1.
  mn1 = (kp1 * en1) + ((ki1 * sn1) / 100) + (kd1 * (en1 - enOld1));
  
  //Filtro digital de suavizado
  //mn1 = alpha*mn1 + (1-alpha)*mn1Old;
  //mn1 = alpha*mn1 + alpha*(1-alpha)*mn1Old + (1-alpha)*(1-alpha) * mn1Oldest; //Debe tener alpha elevada en consecuencia
  //Se actualiza el error anterior por el actual.
  enOld1 = en1;
  mn1Oldest = mn1Old;
  mn1Old = mn1;  
}

//Funcion para mandar la potencia y direccion al motor 1.
void actuador1()
{
  sei();
  interrupts();
  //Condicional por si sobrepasa los limites de velocidad máxima.
  if (mn1 > 255 || mn1 < -255)
  {
    valorPWM1 = 80;
    //Escribe en los pines del PWM el valor seleccionado.
    analogWrite(pinPWM1, valorPWM1);
  }
  else
  {
    //En caso de no superar la velocidad máxima establece el valor de PWM correspondiente a la velocidad objetivo.
    valorPWM1 = (unsigned char)fabs(mn1);
    //Escribe en los pines del PWM el valor seleccionado.
    analogWrite(pinPWM1, valorPWM1);
  }
  //Se manda la direccion del PWM1
  if (mn1 >= 0)
  {
    //Si el valor de PWM a establecer es positivo, envia una señal verdadera para sentido positivo.
    digitalWrite(dirPWM1, HIGH);
  }
  else
  {
    //En caso contrario si el valor de PWM a establecer es negativo, envia una señal falsa para sentido negativo.
    digitalWrite(dirPWM1, LOW);
  }
}


//Funcion PID 2
void PIDControl2()
{
  sei();
  interrupts();
  //Calculo del sumatorio del error.
  sn2 = sn2 + en2;

  //Condicionales por si el error sobresale de los limites de velocidad maxima del motor 2.
  if (sn2 > snmax)
  {
    sn2 = snmax;
  }
  else if (sn2 < snmin)
  {
    sn2 = snmin;
  }
  
  //Calculo del valor PWM.
  mn2 = (kp2 * en2) + ((ki2 * sn2) / 100) + (kd2 * (en2 - enOld2));
  
  //Filtro digital de suavizado
  //mn2 = alpha*mn2 + (1-alpha)*mn2Old; //Debe tener alpha baja en consecuencia
  //mn2 = alpha*mn2 + alpha*(1-alpha)*mn2Old + (1-alpha)*(1-alpha) * mn2Oldest; //Debe tener alpha elevada en consecuencia
  //Se actualiza el error anterior por el actual.
  enOld2 = en2;
  mn2Oldest = mn2Old;
  mn2Old = mn2;  
}

//Funcion para mandar la potencia y direccion al motor 2.
void actuador2()
{
  sei();
  interrupts();
  //Condicional por si sobrepasa los limites de velocidad máxima.
  if (mn2 > 255 || mn2 < -255)
  {
    valorPWM2 = 80;
    //Escribe en los pines del PWM el valor seleccionado.
    analogWrite(pinPWM2, valorPWM2);
  }
  else
  {
    //En caso de no superar la velocidad máxima establece el valor de PWM correspondiente a la velocidad objetivo.
    valorPWM2 = (unsigned char)fabs(mn2);
    //Escribe en los pines del PWM el valor seleccionado.
    analogWrite(pinPWM2, valorPWM2);
  }
  //Mandamos la direccion del PWM2
  if (mn2 >= 0)
  {
    //Si el valor de PWM a establecer es positivo, envia una señal verdadera para sentido positivo.
    digitalWrite(dirPWM2, HIGH);
  }
  else
  {
    //En caso contrario si el valor de PWM a establecer es negativo, envia una señal falsa para sentido negativo.
    digitalWrite(dirPWM2, LOW);
  } 
}

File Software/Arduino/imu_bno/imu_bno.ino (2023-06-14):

#include <SoftwareSerial.h>
#include <Adafruit_Sensor.h>
#include <Adafruit_BNO055.h>
#include <utility/imumaths.h>

// Define the pins for the UART communication
const int RX_PIN = 18;
const int TX_PIN = 19;

// Create a software serial object to communicate with the sensor
SoftwareSerial sensorSerial(RX_PIN, TX_PIN);

// Create an object to communicate with the BNO055 sensor
Adafruit_BNO055 bno = Adafruit_BNO055(55);

void setup() {
  // Start the serial communication with the computer
  Serial.begin(9600);

  // Start the serial communication with the sensor
  sensorSerial.begin(9600);

  // Initialize the BNO055 sensor
  if(!bno.begin())
  {
    Serial.println("Failed to initialize BNO055!");
    while(1);
  }
  // Set the operation mode to IMU (no magnetometer)
  bno.setMode(OPERATION_MODE_IMUPLUS);
}

void loop() {
  // Read the orientation data from the sensor
  sensors_event_t event;
  bno.getEvent(&event);

  // Print the orientation data to the serial monitor
  Serial.print("Orientation: ");
  Serial.print(event.orientation.x);
  Serial.print(",");
  Serial.print(event.orientation.y);
  Serial.print(",");
  Serial.println(event.orientation.z);

  // Wait a short time before reading again
  delay(100);
}

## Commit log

2019-07-19 Updating list of material
    [Material.xlsx, Materials.csv]
2019-07-19 Changing list of material
    [Materials.csv, Materials.xlsx]
2019-07-19 Updating materials
    [Material.xlsx, Materials.xlsx]
2020-09-22 Remove files and materials modification
    [Material.xlsx]
2020-09-24 Codes update
    Addition of the LabVIEW GUI, the OpenUMARov Python node and the nmea_navsat_driver node for GPS, and changes of the Arduino code.
    [Material.xlsx]
2020-10-08 Arduino codes changes
2022-10-05 Nodo para uso con ROS2 Humble
    Nodo de Python junto con el archivo de Arduino para su uso con ROS2 Humble.
2022-10-10 Código actualizado y ordenado
    Se han ordenado una serie de variables, actualizado el formato de datos mostrados por terminal y quitado errores.
    [ROS2UMARov.py]
2022-10-27 Rover URDF
    Se incluye el URDF del Open UMA Rov para posteriores simulaciones
    [basic_mobile_bot_v1.urdf]
2022-10-27 Adición del URDF
2022-10-27 Joystick Control Driver
2022-10-28 Fixed issues with Buffer overlflows
    Now the Rover works flawlessly without any interruption or delays
    [ROS2UMARov.py]
2022-11-18 Gazebo SDF Model Implemented
    [arm_base.stl, bicep.stl, elbow.stl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]
2022-11-22 Removing materials not necessary in this branch.
2022-11-22 Updated package with SDF Files and URDF
    [model (copy).sdf, model2.sdf]
2022-11-22 urdf and sdf models adapted to nav2
    This content must be placed in your "nav2_brigup" directory.
    [Open_UMA_Extended.urdf, model-1_4.sdf, model.sdf]
2022-11-24 Filtro digital introducido en el código Arduino
    Se introduce un filtro digital para obtener una respuesta más suave debido a que en cambios bruscos de consigna el controlador no era capaz de alcanzar esta consigna debido al elevado error provocado.
    [OpenUMARov.ino]
2022-11-25 Updated PI Values and corrected digital filter
    [OpenUMARov.ino]
2022-11-25 Updated and corrected some issues
    [OpenUMARov.ino]
2022-11-28 Updated controller and publish encoder info
    Updated the PI in the Arduino code and added a digital filter to smooth the PWM signal sent to the motors in order to avoid an unstable system.
    The ROS2 node now receives information from the Arduino with information about the encoders. This information is later published in newly made topics.
    [OpenUMARov.ino, ROS2UMARov.py]
2022-11-28 Updated values to lower latency
    Updated ROS2 Node to lower the spin frequency and updated to Arduino code to have lower latency by updating the digital filter
2022-12-21 Diseños 3D para Rover
    [SoporteRasp3.1.SLDPRT, SoporteRasp3.1.STL, SoporteRasp3.SLDPRT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]
2023-03-31 Engranajes dedicados a la correa de OPENUMA
    [Engranaje.SLDPRT, Engranaje_Simple.SLDPRT, gt2-parametric-pulley.SLDPRT]
2023-05-15 Updated folders and files required to run OPENUMA with ROS2
    [Engranaje.SLDPRT, Engranaje_Sin_Borde.SLDPRT, Open_UMA_Extended.urdf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]
2023-06-14 Updated the structure of the repository
    [Engranaje.SLDPRT, Engranaje_Sin_Borde.SLDPRT, Material.xlsx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]
2023-06-14 Added files for IMU
    [imu_holder.stl]
